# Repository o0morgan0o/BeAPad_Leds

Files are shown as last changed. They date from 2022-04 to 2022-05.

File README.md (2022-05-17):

# BeAPad Led Project

Project for touch sensors combined to Neopixels and RTP Midi for controlling Light and music via midiMessages across wifi.

## Materials:

- ESP32 Microcontroller (WROOM
  DEVKIT_V1) [amazon](https://www.amazon.fr/SP-Cow-ESP-32S-d%C3%A9veloppement-Bluetooth-d%C3%A9nergie/dp/B07VJ34N2Q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) [aliexpress](https://fr.aliexpress.com/item/1005001929935550.html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)
- MPR121 Touch Shield [amazon](https://www.amazon.fr/Adafruit-12-Key-Capacitive-Sensor-Breakout/dp/B00SK8PVNA)
- WS2812E leds [amazon](https://www.amazon.fr/gp/product/B088BRY2SH/ref=ppx_yo_dt_b_asin_title_o07_s00?ie=UTF8&th=1) **<u>MUST BE 60Leds/m for easy soldering on PCB</u>**
- Battery 1100 mAh Lithium 1S 3c
- 1 Capacitor 1000uF
- Steel plates
- Optional : Power Supply 5V 10A or 4 AA Batteries

## Usage

Use RTP-Midi software in windows to listen for midi signals over Wi-Fi.
(software : https://www.tobias-erichsen.de/software/rtpmidi/rtpmidi-tutorial.html)

Set RTP-Midi device to address `192.168.0.4` (address set to client by ESP32 DHCP)

## Ableton Setup

In order to send midi towards the controller, on each midi track, set an instrument rack with:
- External instrument to RTP_Midi Receiver session
- Your drum rack with active notes mentioned in next section

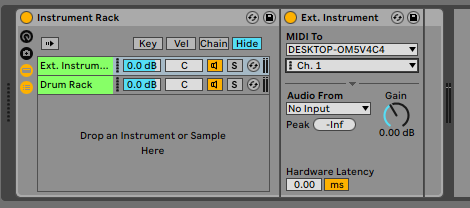
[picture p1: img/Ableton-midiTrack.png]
ableton


### Mapping MidiReceive

```
Each MidiNote Receveid is connected to a specific light effect on board
 _______________________________________
|  | | | |  |  | | | | | |  |  | | | |  |
|  | | | |  |  | | | | | |  |  | | | |  |
|  | | | |  |  | | | | | |  |  | | | |  |
|  |_| |_|  |  |_| |_| |_|  |  |_| |_|  |
|   |   |   |   |   |   |   |   |   |   |
|   |   |   |   |   |   |   |   |   |   |
|___|___|___|___|___|___|___|___|___|___|

TOUCH SENSOR BOARDS ARE CONNECTED TO THE FOLLOWING MIDI NOTES:
  The boards always send the same midiNote:
    -> C4 ( MIDI 60 )      Board 1
    -> C#4 ( MIDI 61 )     Board 2
    -> D4 ( MIDI 62 )      Board 3
    -> D#4 ( MIDI 63 )     Board 4
    -> E4 ( MIDI 64 )      Board 5
    -> F4 ( MIDI 65 )      Board 6
    -> F#4 ( MIDI 66 )     Board 7
    -> G4 ( MIDI 67 )      Board 8
    -> G#4 ( MIDI 68 )     Board 9
    -> A4 ( MIDI 69 )      Board 10
    -> A#4 ( MIDI 70 )     Board 11
    
WHEN SHIFT IS PRESSED (BOARD 12) THE SENSOR BOARDS CAN SEND THESE MIDI NOTES:
    ->  G#6 ( MIDI 80 )     Board 1
    ->  A6 ( MIDI 81 )      Board 2
    ->  A#6 ( MIDI 82 )     Board 3
    ->  B6 ( MIDI 83 )      Board 4
    ->  C7 ( MIDI 84 )      Board 5
    ->  C#7 ( MIDI 85 )     Board 6
    ->  D7 ( MIDI 86 )      Board 7
    ->  D#7 ( MIDI 87 )     Board 8
    ->  E7 ( MIDI 88 )      Board 9
    ->  F7 ( MIDI 89 )      Board 10
    ->  F#7 ( MIDI 90 )     Board 11

*****************************
LIGHT_STRATEGIES PER CHANNEL:
-> One color per channel
*****************************
    CHANNEL 1 | FULL_LIGHT
    CHANNEL 2 | FADE_OUT
    CHANNEL 3 | SERPENTIN
    CHANNEL 4 | FLASH_TOWARDS_EXTERIOR
    CHANNEL 5 | NOTHING YET
    CHANNEL 6 | NOTHING YET
    CHANNEL 7 | NOTHING YET
    CHANNEL 8 | NOTHING YET
    
******************************
SPECIAL EFFECTS
-> Color can be change by midi_note value
-> Luminosity can be change by velocity value
******************************

    CHANNEL 9  | STROMBOSCOPE
    CHANNEL 10 | NOTHING YET
    CHANNEL 11 | NOTHING YET
    CHANNEL 12 | NOTHING YET
    CHANNEL 13 | NOTHING YET
    CHANNEL 14 | NOTHING YET
    CHANNEL 15 | NOTHING YET
    CHANNEL 16 | NOTHING YET

```

## Hardware

### LedBoards:

(See EasyEDA project in "Resources_PCB_Schematics")

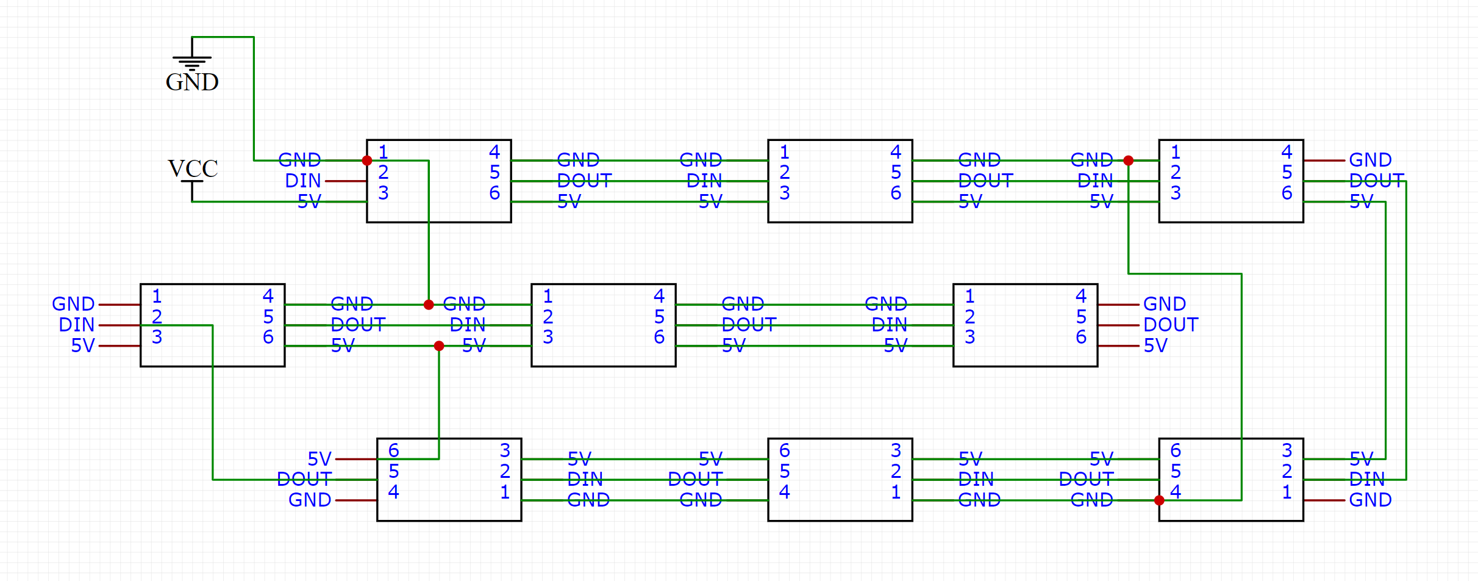
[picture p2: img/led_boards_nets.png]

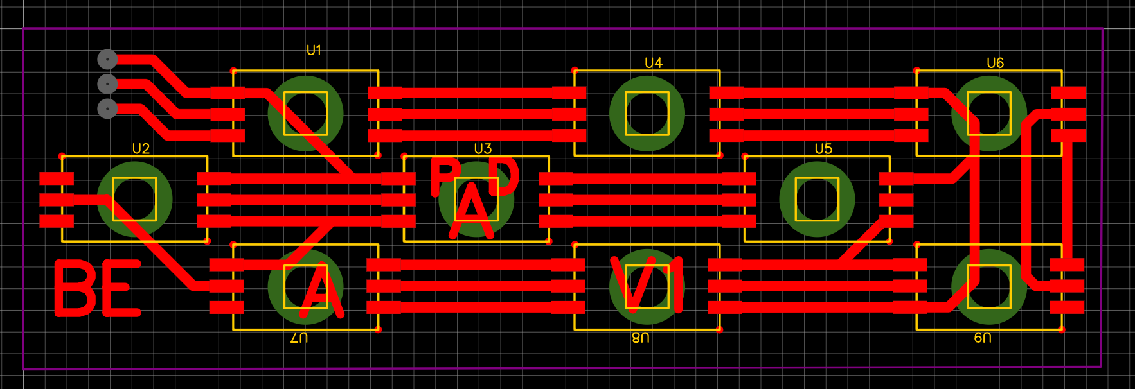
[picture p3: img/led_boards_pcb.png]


**Warning: Orientation of led change across the board (see real reference below)**

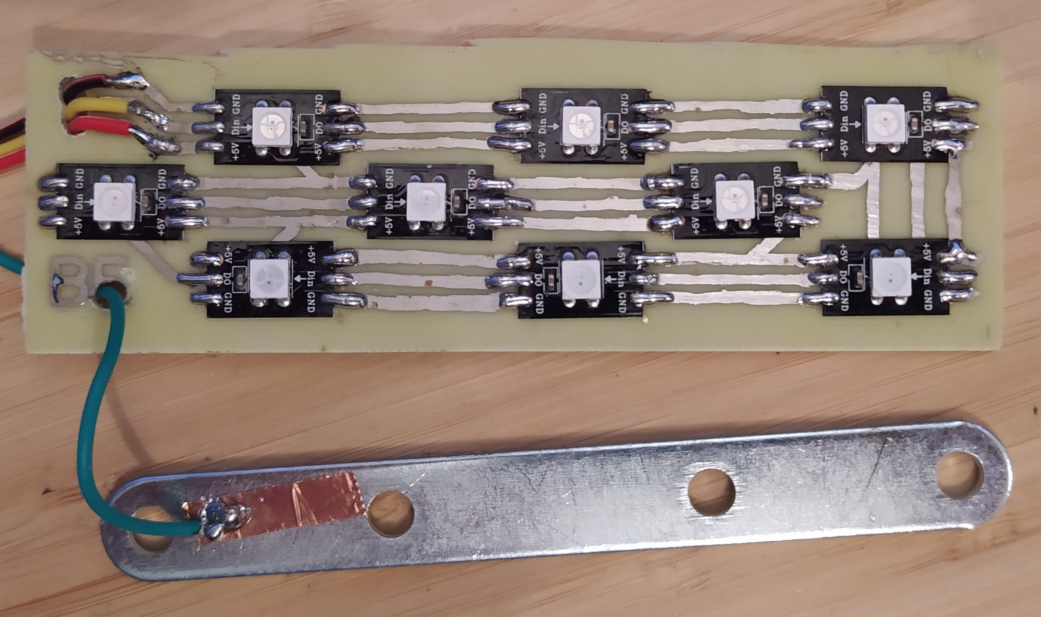
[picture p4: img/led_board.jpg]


### Controller Board

(See KiCad project in "Resources_PCB_Schematics")

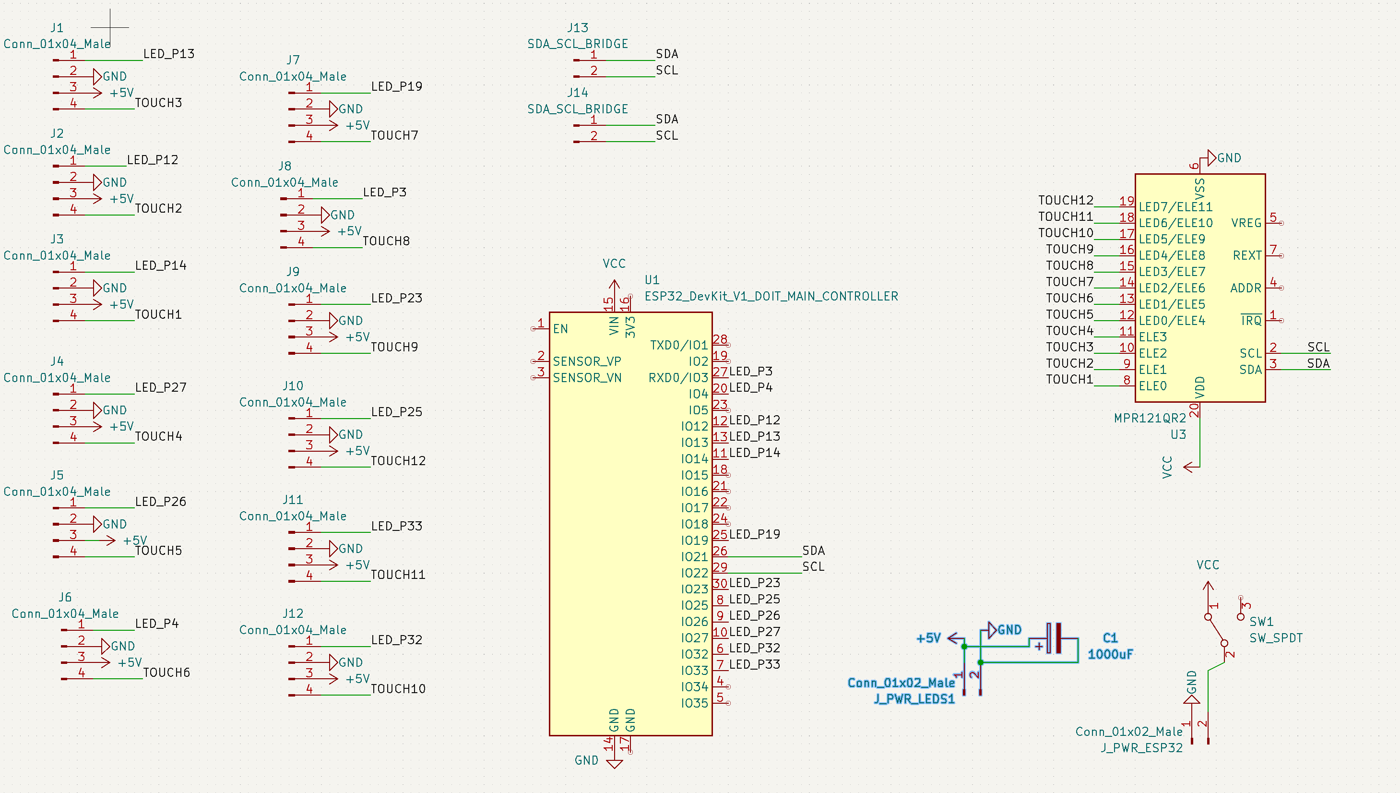
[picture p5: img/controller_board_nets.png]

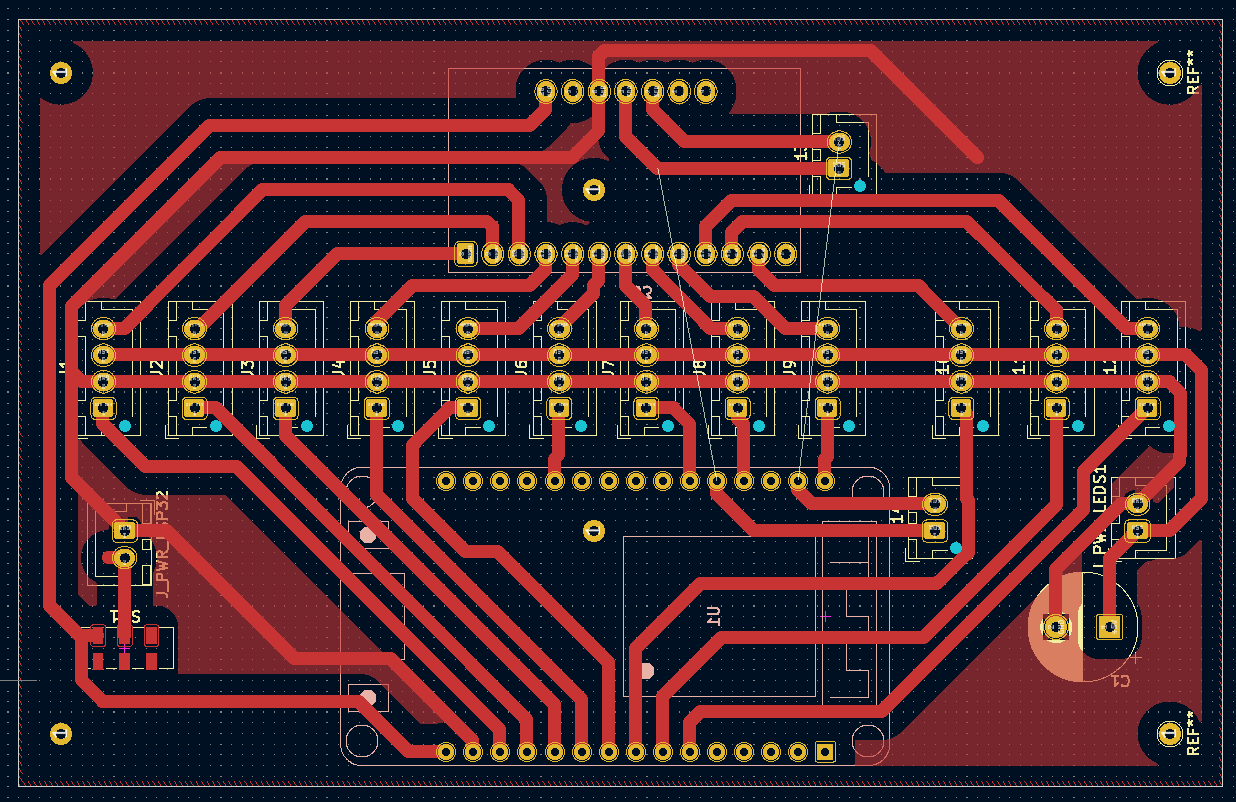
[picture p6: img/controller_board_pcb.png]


**Real prototype**

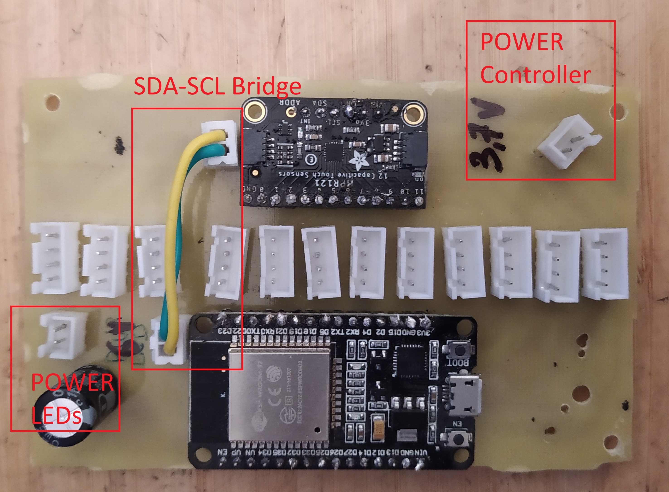
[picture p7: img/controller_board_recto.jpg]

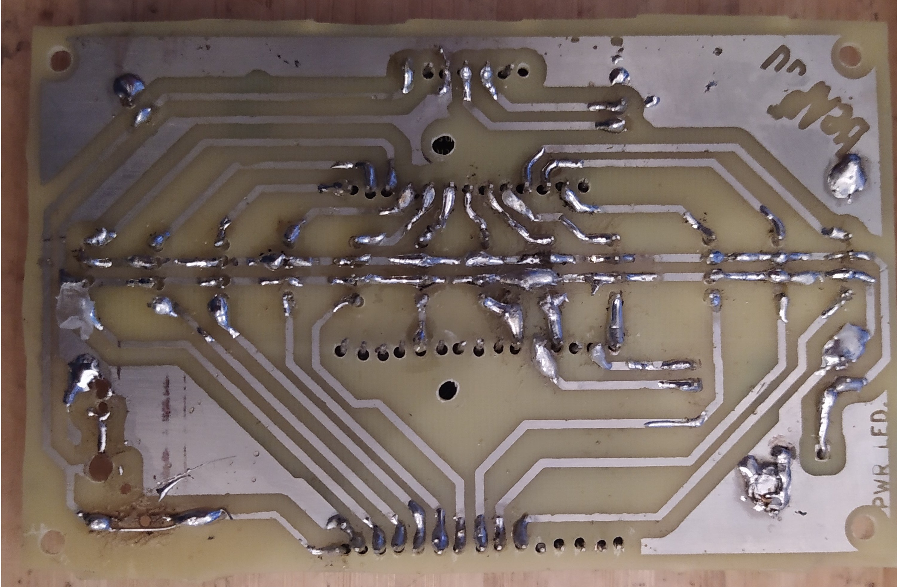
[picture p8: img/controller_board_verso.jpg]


### 3D Models

Very basic holders can be found in Resources_3D_printing.

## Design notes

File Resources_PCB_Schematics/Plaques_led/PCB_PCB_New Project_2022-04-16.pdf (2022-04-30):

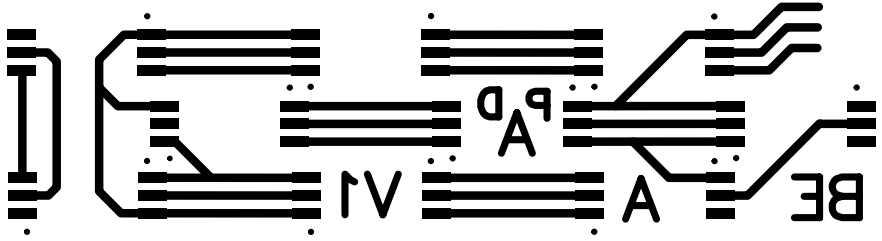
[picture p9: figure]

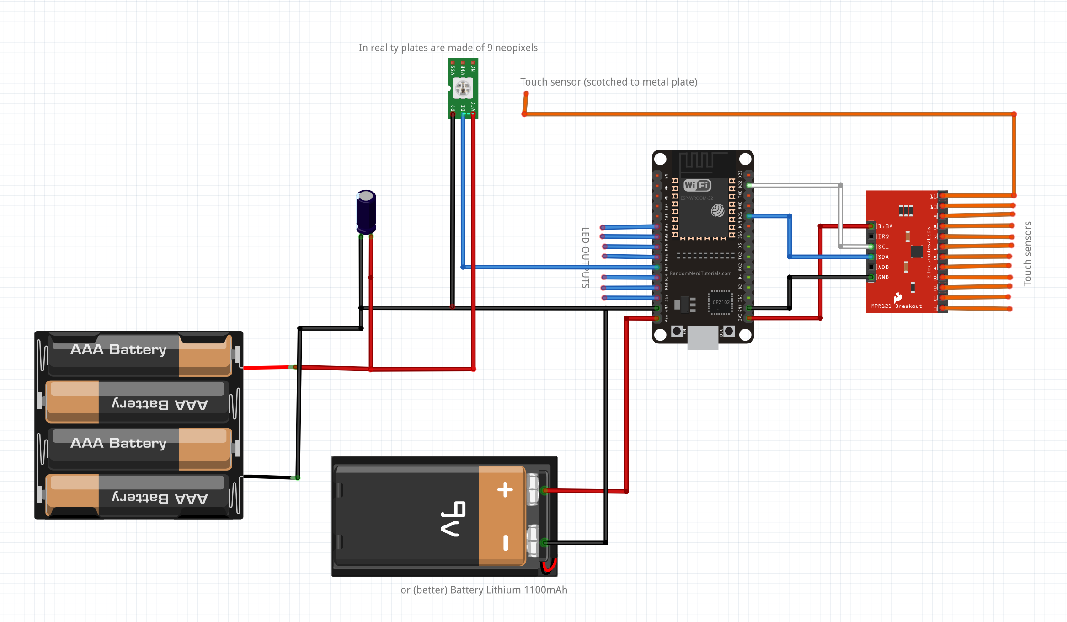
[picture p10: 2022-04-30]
Resources_PCB_Schematics/schema_cablages.png

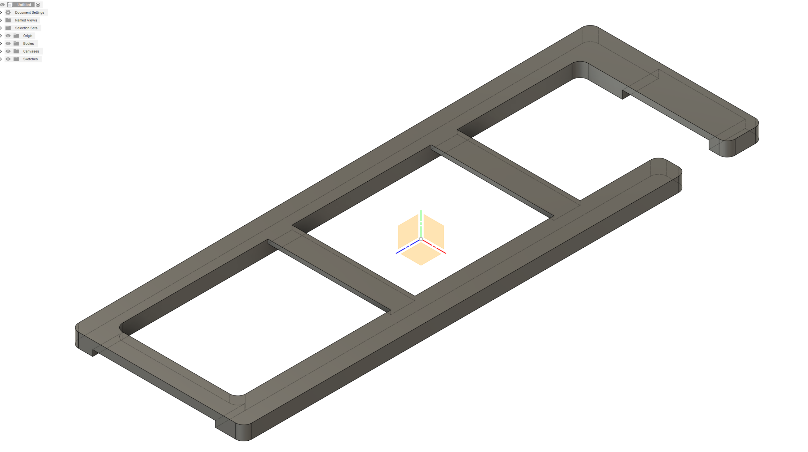
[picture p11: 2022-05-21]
img/calage-plaques.png

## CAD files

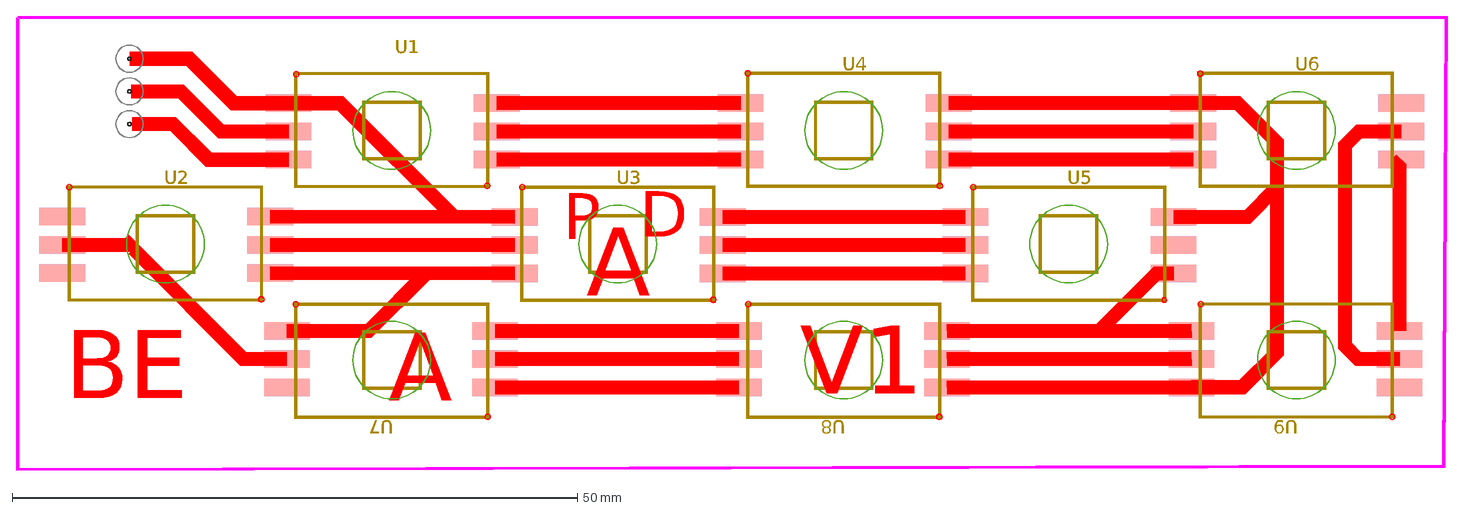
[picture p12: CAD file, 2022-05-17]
Resources_PCB_Schematics/Plaques_led/PCB_New Project_2022-05-17.dxf
BE
A
P
D
V1
U1
U2
U3
U4
U5
U6
U7
U8
U9

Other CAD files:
Resources_3D_printing/Calage_plaques.f3d

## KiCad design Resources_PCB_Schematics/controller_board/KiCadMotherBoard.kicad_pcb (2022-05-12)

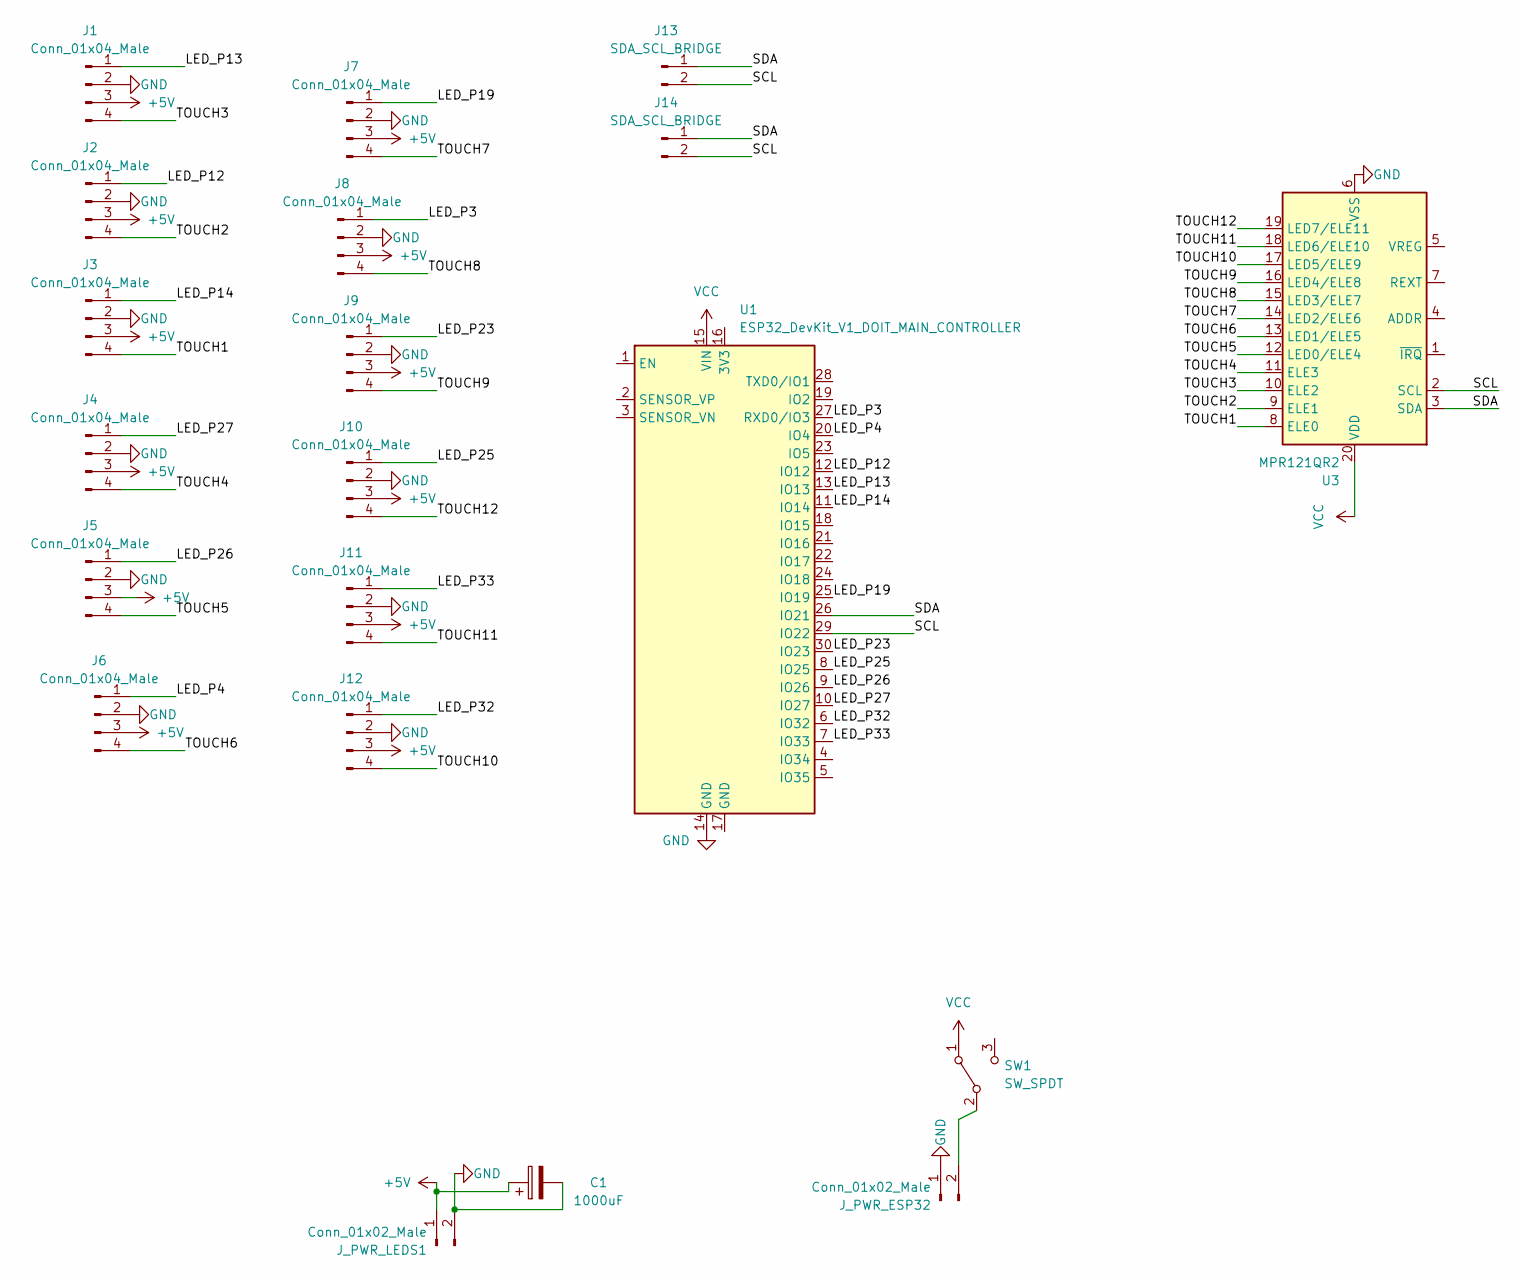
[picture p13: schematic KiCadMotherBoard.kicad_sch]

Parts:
C1: 1000uF; CP_Radial_D10.0mm_P5.00mm
J1, J2, J3, J4, J5, J6, J7, J8, J9, J10, J11, J12: Conn_01x04_Male; JST_XH_B4B-XH-AM_1x04_P2.50mm_Vertical
J13, J14: SDA_SCL_BRIDGE; JST_XH_B2B-XH-AM_1x02_P2.50mm_Vertical
J_PWR_ESP32: Conn_01x02_Male; JST_XH_B2B-XH-A_1x02_P2.50mm_Vertical
J_PWR_LEDS1: Conn_01x02_Male; JST_XH_B2B-XH-A_1x02_P2.50mm_Vertical
SW1: SW_SPDT; SW_DPDT_CK_JS202011JCQN
U1: ESP32_DevKit_V1_DOIT_MAIN_CONTROLLER; esp32_devkit_v1_doit
U3: MPR121QR2; custom-mpr121

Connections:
+5V: C1.1, J1.3, J2.3, J3.3, J4.3, J5.3, J6.3, J7.3, J8.3, J9.3, J10.3, J11.3, J12.3, J_PWR_LEDS1.1
/LED_P3: J8.1, U1.27 (RXD0/IO3)
/LED_P4: J6.1, U1.20 (IO4)
/LED_P12: J2.1, U1.12 (IO12)
/LED_P13: J1.1, U1.13 (IO13)
/LED_P14: J3.1, U1.11 (IO14)
/LED_P19: J7.1, U1.25 (IO19)
/LED_P23: J9.1, U1.30 (IO23)
/LED_P25: J10.1, U1.8 (IO25)
/LED_P26: J5.1, U1.9 (IO26)
/LED_P27: J4.1, U1.10 (IO27)
/LED_P32: J12.1, U1.6 (IO32)
/LED_P33: J11.1, U1.7 (IO33)
/SCL: J13.2, J14.2, U1.29 (IO22), U3.2 (SCL)
/SDA: J13.1, J14.1, U1.26 (IO21), U3.3 (SDA)
/TOUCH1: J3.4, U3.8 (ELE0)
/TOUCH2: J2.4, U3.9 (ELE1)
/TOUCH3: J1.4, U3.10 (ELE2)
/TOUCH4: J4.4, U3.11 (ELE3)
/TOUCH5: J5.4, U3.12 (LED0/ELE4)
/TOUCH6: J6.4, U3.13 (LED1/ELE5)
/TOUCH7: J7.4, U3.14 (LED2/ELE6)
/TOUCH8: J8.4, U3.15 (LED3/ELE7)
/TOUCH9: J9.4, U3.16 (LED4/ELE8)
/TOUCH10: J12.4, U3.17 (LED5/ELE9)
/TOUCH11: J11.4, U3.18 (LED6/ELE10)
/TOUCH12: J10.4, U3.19 (LED7/ELE11)
GND: C1.2, J1.2, J2.2, J3.2, J4.2, J5.2, J6.2, J7.2, J8.2, J9.2, J10.2, J11.2, J12.2, J_PWR_ESP32.1, J_PWR_LEDS1.2, U1.14 (GND), U3.6 (VSS)
unnamed: J_PWR_ESP32.2, SW1.2 (B)
VCC: SW1.1 (A), U1.15 (VIN), U3.20 (VDD)

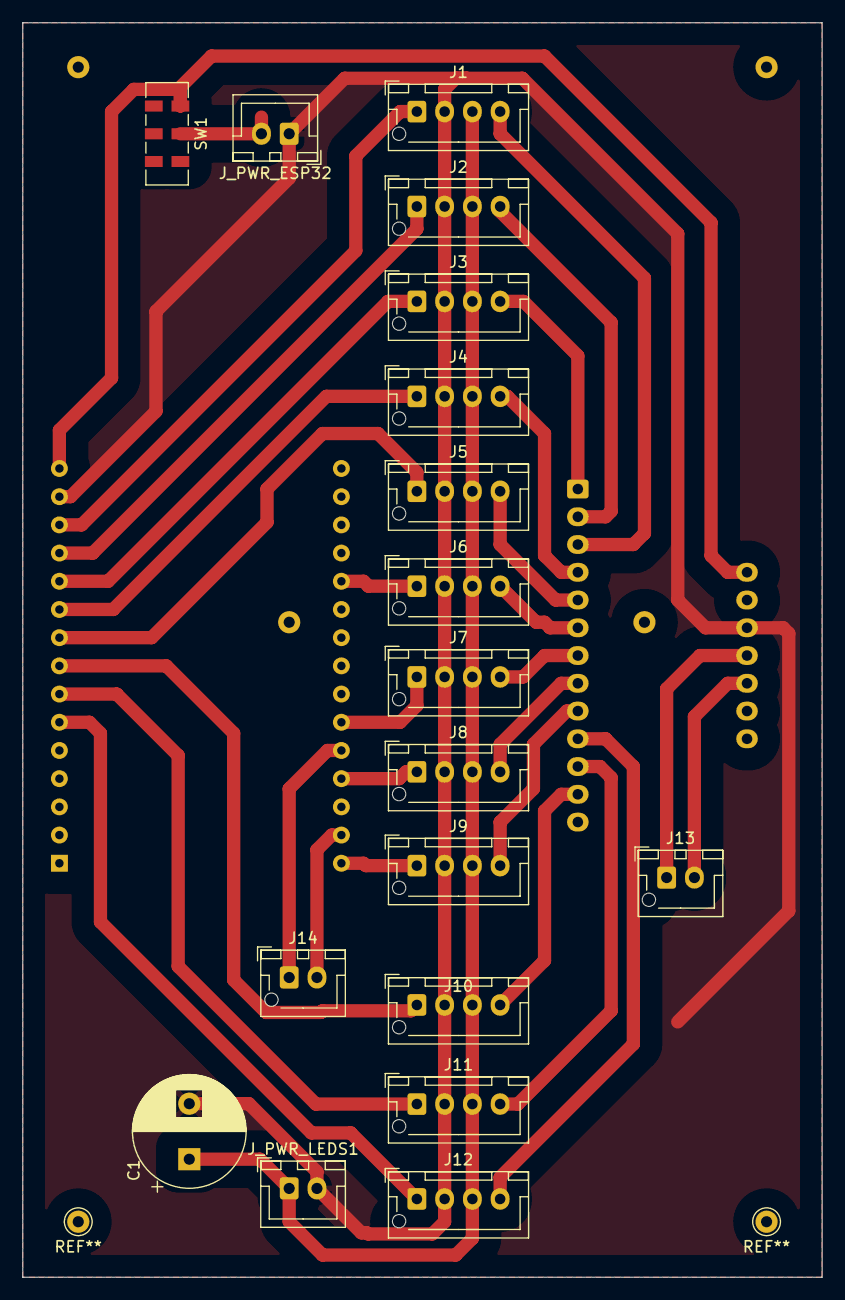
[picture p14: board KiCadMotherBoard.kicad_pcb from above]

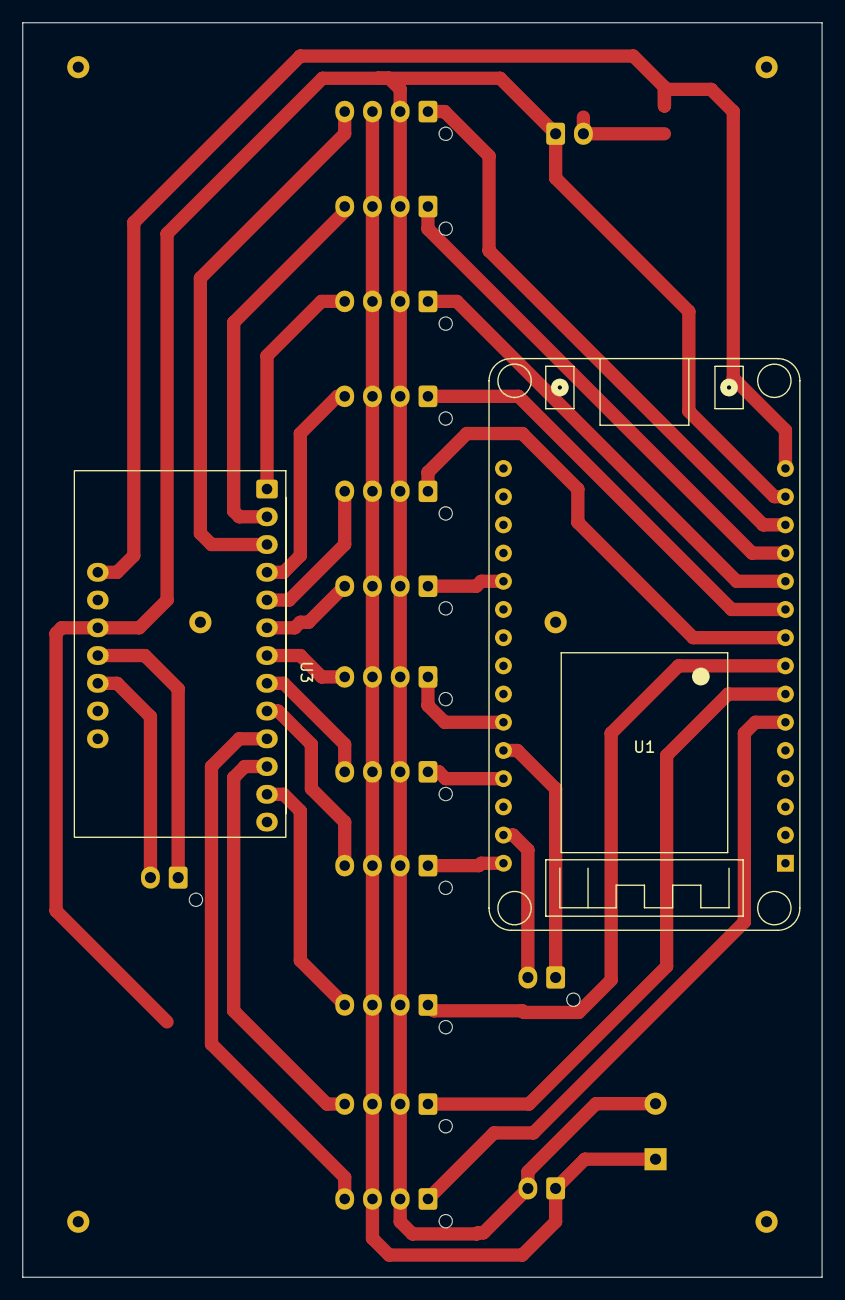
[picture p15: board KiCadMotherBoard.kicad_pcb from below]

Board: 2 copper layers, 72.0 x 113.0 mm, 20 parts (2 on the bottom side), 30 nets.

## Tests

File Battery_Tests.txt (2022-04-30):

Program:
Blend -> CRGB:AliceBlue -> CRGB:Red

	ESP32 USB Power
	Leds : 4 AA lr6 Eco+
		=> 80 min couleurs deviennents vertes et rougae
		=> 120 min jaune et rouge. Affaiblissement important
		=> 140 min leds complétements rouges

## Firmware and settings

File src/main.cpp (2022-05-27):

/**
 * BeAPadProject
 * Morgan Thibert - 2022
 *
 * MidiController with with communication via RTP-Midi on Wifi controlled by capacitive sensors
 *
 * Interesting resources:
 * http://ww1.microchip.com/downloads/en/Appnotes/Capacitive-Touch-Sensor-Design-Guide-DS00002934-B.pdf
 */

#include <AppleMidi.h>
#include <WiFiUdp.h>
#include "AccessPoint.h"
#include "Debug_Helper.h"
#include "LightStrategy_Factory.h"
#include "MidiKeyReceiver.h"
#include "Midi_Handler.h"
#include "Debug_Helper_Serial.h"
#include "Debug_Helper_Inactive.h"
#include "RTP_Midi_MidiHandler.h"
#include "DebugHelper_WebSocket.h"
#include "MidiKeySender.h"
#include <Wire.h>
#include "LedBoard_Store_NeoPixelStore.h"
#include "NeoPixelBoard.h"
#include "NeoPixelBoardsManager.h"
#include "CapacitiveTouch_Dispatcher.h"
#include "Capacitive_Sensor.h"
#include "MPR121_Sensor.h"
#include "main_constants.h"

#define MPR_TOUCH_PIN_CONNECTED_TO_BOARD_0 2
#define MPR_TOUCH_PIN_CONNECTED_TO_BOARD_1 1
#define MPR_TOUCH_PIN_CONNECTED_TO_BOARD_2 0
#define MPR_TOUCH_PIN_CONNECTED_TO_BOARD_3 3
#define MPR_TOUCH_PIN_CONNECTED_TO_BOARD_4 4
#define MPR_TOUCH_PIN_CONNECTED_TO_BOARD_5 5
#define MPR_TOUCH_PIN_CONNECTED_TO_BOARD_6 6
#define MPR_TOUCH_PIN_CONNECTED_TO_BOARD_7 7
#define MPR_TOUCH_PIN_CONNECTED_TO_BOARD_8 8
#define MPR_TOUCH_PIN_CONNECTED_TO_BOARD_9 11
#define MPR_TOUCH_PIN_CONNECTED_TO_BOARD_10 10
APPLEMIDI_CREATE_INSTANCE(WiFiUDP, AppleMIDI, "AppleMIDI-ESP32", DEFAULT_CONTROL_PORT);
//
AccessPoint *accessPoint;
Debug_Helper *debugHelper;
Debug_Helper *inactiveDebugHelper;
LedBoard_Store_Interface *ledBoardStore;
LedBoardsManager *ledBoardsManager;
LightStrategy_Factory *lightStrategyFactory;
SpecialEffect_Factory *specialEffectFactory;
MidiKeyReceiver *midiReceiver;
MidiKeySender *midiSender;
ICapacitiveTouch_Dispatcher *capacitiveTouchDispatcher;
Midi_Handler *midiHandler;
Capacitive_Sensor *touchSensor;

void setup() {

  // **************************
  // DEBUG HELPER
  //    debugHelper = new Debug_Helper();
  //    debugHelper = new Debug_Helper_Inactive();
  //    debugHelper = new DebugHelper_WebSocket();
  //    debugHelper = new Debug_Helper_Serial();
  // COMMENT FOLLOWING 2 LINES TO REACTIVATE DEBUG MODE
  inactiveDebugHelper = new Debug_Helper_Inactive();
  debugHelper = inactiveDebugHelper;

  // *************************
  // ACCESS POINT
  accessPoint = new AccessPoint();

  // **************************
  // CREATION OF LIGHT STRATEGY AND SPECIAL EFFECTS FACTORY
  lightStrategyFactory = new LightStrategy_Factory();
  specialEffectFactory = new SpecialEffect_Factory();

  // **************************
  // ADD BOARDS TO STORE
  // NeoPixelBoard 1st param = GPIO Pin
  ledBoardStore = new LedBoard_Store_NeoPixelStore();
  uint8_t NUM_PIXELS_PER_BOARD = 9;
  // NOTE : VERY IMPORTANT TO KEEP THE SAME ORDER OF THE PCB
  ledBoardStore->addBoard(new NeoPixelBoard(32, NUM_PIXELS_PER_BOARD, lightStrategyFactory));
  ledBoardStore->addBoard(new NeoPixelBoard(33, NUM_PIXELS_PER_BOARD, lightStrategyFactory));
  ledBoardStore->addBoard(new NeoPixelBoard(25, NUM_PIXELS_PER_BOARD, lightStrategyFactory));
  ledBoardStore->addBoard(new NeoPixelBoard(23, NUM_PIXELS_PER_BOARD, lightStrategyFactory));
  ledBoardStore->addBoard(new NeoPixelBoard(3, NUM_PIXELS_PER_BOARD, lightStrategyFactory));
  ledBoardStore->addBoard(new NeoPixelBoard(19, NUM_PIXELS_PER_BOARD, lightStrategyFactory));
  ledBoardStore->addBoard(new NeoPixelBoard(4, NUM_PIXELS_PER_BOARD, lightStrategyFactory));
  ledBoardStore->addBoard(new NeoPixelBoard(26, NUM_PIXELS_PER_BOARD, lightStrategyFactory));
  ledBoardStore->addBoard(new NeoPixelBoard(27, NUM_PIXELS_PER_BOARD, lightStrategyFactory));
  ledBoardStore->addBoard(new NeoPixelBoard(14, NUM_PIXELS_PER_BOARD, lightStrategyFactory));
  ledBoardStore->addBoard(new NeoPixelBoard(12, NUM_PIXELS_PER_BOARD, lightStrategyFactory));
  ledBoardStore->addBoard(new NeoPixelBoard(13, NUM_PIXELS_PER_BOARD, lightStrategyFactory));

  // **************************
  // INITIALIZE BOARD MANAGER
  ledBoardsManager = new NeoPixelBoardsManager(ledBoardStore, lightStrategyFactory, specialEffectFactory,
											   debugHelper);
  ledBoardsManager->init();
  ledBoardsManager->giveAllBoardsReferenceOfManager();

  // *************************
  // DEFINITIONS OF STRATEGY FOR EACH BOARD
  // Channel musts be in range 1 - 8

  // *************************************************************************
  // *************************************************************************
  // GONZY !!! C'est ICI QUE TU CHANGES LES COULEURS
  // DDDDDDDDDDDDDDDDDDDDDDDDDDDDDDDDDDDDDDDDDDDDDDDDDDDDDDDD
  // DDDDDDDDDDDDDDDDDDDDDDDDDDDDDDDDDDDDDDDDDDDDDDDDDDDDDDDD
  // DDDDDDDDDDDDDDDDDDDDDDDDDDDDDDDDDDDDDDDDDDDDDDDDDDDDDDDD
  // DDDDDDDDDDDDDDDDDDDDDDDDDDDDDDDDDDDDDDDDDDDDDDDDDDDDDDDD
  // DDDDDDDDDDDDDDDDDDDDDDDDDDDDDDDDDDDDDDDDDDDDDDDDDDDDDDDD
  // DDDDDDDDDDDDDDDDDDDDDDDDDDDDDDDDDDDDDDDDDDDDDDDDDDDDDDDD
  // DDDDDDDDDDDDDDDDDDDDDDDDDDDDDDDDDDDDDDDDDDDDDDDDDDDDDDDD
  // DDDDDDDDDDDDDDDDDDDDDDDDDDDDDDDDDDDDDDDDDDDDDDDDDDDDDDDD
  // DDDDDDDDDDDDDDDDDDDDDDDDDDDDDDDDDDDDDDDDDDDDDDDDDDDDDDDD
  // List of Predefined color names : https://github.com/FastLED/FastLED/wiki/Pixel-reference
  // Colors can be changed here by hexValue CRGB{0xffffff}, or by predefined Colors CRGB::Red, or by rgb values CRGB{255,255,0};
  ledBoardsManager->setLightStrategyForChannel(1, LIGHT_STRATEGIES::STRATEGY_FULL_LIGHT, CRGB::Red);
  ledBoardsManager->setLightStrategyForChannel(2, LIGHT_STRATEGIES::STRATEGY_FADE_OUT, CRGB{60,87,13});
  ledBoardsManager->setLightStrategyForChannel(3, LIGHT_STRATEGIES::STRATEGY_SERPENTIN, CRGB{76,125,117});
  ledBoardsManager->setLightStrategyForChannel(4, LIGHT_STRATEGIES::STRATEGY_FLASH_TOWARDS_EXTERIOR, CRGB::BlueViolet);
  ledBoardsManager->setShiftColor(CRGB::White); // Shift Color
  // *************************************************************************
  // *************************************************************************

  // TODO : Make more Strategies
  // STRATEGY_FADE_OUT_SLOW
  // STRATEGY_EXPANSION FROM CENTER TO EXTERIOR
  // SPECIAL_EFFECTS GLOBAL WAVE

  // **************************
  // DEFINITIONS OF SPECIAL EFFECTS STRATEGY
  // Channel must be in range 9 - 16
  // Special Effects Strategy don't need color. Special Effects handled HSV Colors, where:
  // H (color tone) is set by noteNumber
  // S (color saturation) is fixed at arbitrary value
  // V (color luminosity) is set by velocity
  ledBoardsManager->setSpecialEffectStrategyForChannel(9, SPECIAL_EFFECT_STRATEGY::SPECIAL_EFFECT_STROMBOSCOPE);

  // ****************************
  // MIDI KEY RECEIVER
  // explanations: connectBoardToReceiveMidiKey(60, 0);
  // it means when MidiNote 60 is received a triggerOnSignalIsSendOn board 0
  midiReceiver = new MidiKeyReceiver(ledBoardsManager, inactiveDebugHelper);
  midiReceiver->connectBoardToReceiveMidiKey(0, 60);
  midiReceiver->connectBoardToReceiveMidiKey(1, 61);
  midiReceiver->connectBoardToReceiveMidiKey(2, 62);
  midiReceiver->connectBoardToReceiveMidiKey(3, 63);
  midiReceiver->connectBoardToReceiveMidiKey(4, 64);
  midiReceiver->connectBoardToReceiveMidiKey(5, 65);
  midiReceiver->connectBoardToReceiveMidiKey(6, 66);
  midiReceiver->connectBoardToReceiveMidiKey(7, 67);
  midiReceiver->connectBoardToReceiveMidiKey(8, 68);
  midiReceiver->connectBoardToReceiveMidiKey(9, 69);
  midiReceiver->connectBoardToReceiveMidiKey(10, 70);

  // ***************************
  // MIDI KEY SENDER
  // explanations : connectBoardToSendMidiKey(1, 4 ,87)
  // it means that touchPin1 (in MPR121) is connected to board 4
  // ,and it will send midiNote 87 when touched
  // Last board (11 from index 0) is not connected to midiSend or touchPin because it acts as a shift button
  midiSender = new MidiKeySender(ledBoardsManager, debugHelper);
  midiSender->connectBoardToSendMidiKey(MPR_TOUCH_PIN_CONNECTED_TO_BOARD_0, 0, 60, 80);
  midiSender->connectBoardToSendMidiKey(MPR_TOUCH_PIN_CONNECTED_TO_BOARD_1, 1, 61, 81);
  midiSender->connectBoardToSendMidiKey(MPR_TOUCH_PIN_CONNECTED_TO_BOARD_2, 2, 62, 82);
  midiSender->connectBoardToSendMidiKey(MPR_TOUCH_PIN_CONNECTED_TO_BOARD_3, 3, 63, 83);
  midiSender->connectBoardToSendMidiKey(MPR_TOUCH_PIN_CONNECTED_TO_BOARD_4, 4, 64, 84);
  midiSender->connectBoardToSendMidiKey(MPR_TOUCH_PIN_CONNECTED_TO_BOARD_5, 5, 65, 85);
  midiSender->connectBoardToSendMidiKey(MPR_TOUCH_PIN_CONNECTED_TO_BOARD_6, 6, 66, 86);
  midiSender->connectBoardToSendMidiKey(MPR_TOUCH_PIN_CONNECTED_TO_BOARD_7, 7, 67, 87);
  midiSender->connectBoardToSendMidiKey(MPR_TOUCH_PIN_CONNECTED_TO_BOARD_8, 8, 68, 88);
  midiSender->connectBoardToSendMidiKey(MPR_TOUCH_PIN_CONNECTED_TO_BOARD_9, 9, 69, 89);
  midiSender->connectBoardToSendMidiKey(MPR_TOUCH_PIN_CONNECTED_TO_BOARD_10, 10, 70, 90);
  midiSender->connectBoardToSendMidiKey(MPR_TOUCH_PIN_CONNECTED_TO_BOARD_11_SHIFT_PIN, 11, NO_MIDI_TRIGGER_FOR_BOARD,
										NO_MIDI_TRIGGER_FOR_BOARD);

  // **************************
  // RTP_MIDI
  midiHandler = new RTP_Midi_MidiHandler(midiReceiver, midiSender, debugHelper, &AppleMIDI, &AppleAppleMIDI);
  midiHandler->init();
  // set eventListeners
  // TODO implements MIDI_CC change (maybe for controlling the colors)
  AppleMIDI.setHandleNoteOn([](byte channel, byte note, byte velocity) {
	// channels [1 - 8] are reserved for lightStrategies
	// channels [9 - 16] are reserved for special effects
	if (channel <= 8) midiHandler->handleOn(channel, note, velocity);
	else midiHandler->handleOnSpecialEffect(channel, note, velocity);
  });
  AppleMIDI.setHandleNoteOff([](byte channel, byte note, byte velocity) {
	if (channel <= 8) midiHandler->handleNoteOff(channel, note, velocity);
	else midiHandler->handleOffSpecialEffect(channel, note, velocity);
  });
  AppleAppleMIDI.setHandleConnected([](const APPLEMIDI_NAMESPACE::ssrc_t &ssrc, const char *name) {
	ledBoardsManager->showBlinkHighPriorityMessage(BlinkHighPriorityMessages::RTP_CONNECTION_SUCCESS);
	midiHandler->handleConnected();
  });
  AppleAppleMIDI.setHandleDisconnected([](const APPLEMIDI_NAMESPACE::ssrc_t &ssrc) {
	ledBoardsManager->showBlinkHighPriorityMessage(BlinkHighPriorityMessages::RTP_CONNECTION_LOST);
	midiHandler->handleDisconnected();
  });

  // **************************
  // TOUCH SENSORS INIT (MPR121)
  // Following strategies are chosen arbitrarily (except for the shift_key_strategy). They can be used when the device is not midi connected
  touchSensor = new MPR121_Sensor();

  // **************************
  // CAPACITIVE TOUCH DISPATCHER
  capacitiveTouchDispatcher = new CapacitiveTouch_Dispatcher(ledBoardsManager, midiHandler, debugHelper, touchSensor);
  capacitiveTouchDispatcher->begin();
  // THRESHOLD: read documentation of MPR121 about the handling of thresholds
  // helpful thread about this : https://forums.adafruit.com/viewtopic.php?t=72025
  // If default values ard OK, comment following line
  // capacitiveTouchDispatcher->setThresholds(20, 10);
  // the following strategies can be ignored because are for use only if no rtp midi is connected
  capacitiveTouchDispatcher->setTriggerOnTouchLightStrategyOnBoard(0, LIGHT_STRATEGIES::STRATEGY_FADE_OUT);
  capacitiveTouchDispatcher->setTriggerOnTouchLightStrategyOnBoard(1, LIGHT_STRATEGIES::STRATEGY_FADE_OUT);
  capacitiveTouchDispatcher->setTriggerOnTouchLightStrategyOnBoard(2, LIGHT_STRATEGIES::STRATEGY_FADE_OUT);
  capacitiveTouchDispatcher->setTriggerOnTouchLightStrategyOnBoard(3, LIGHT_STRATEGIES::STRATEGY_FADE_OUT);
  capacitiveTouchDispatcher->setTriggerOnTouchLightStrategyOnBoard(4, LIGHT_STRATEGIES::STRATEGY_FADE_OUT);
  capacitiveTouchDispatcher->setTriggerOnTouchLightStrategyOnBoard(5, LIGHT_STRATEGIES::STRATEGY_FADE_OUT);
  capacitiveTouchDispatcher->setTriggerOnTouchLightStrategyOnBoard(6, LIGHT_STRATEGIES::STRATEGY_FADE_OUT);
  capacitiveTouchDispatcher->setTriggerOnTouchLightStrategyOnBoard(7, LIGHT_STRATEGIES::STRATEGY_FADE_OUT);
  capacitiveTouchDispatcher->setTriggerOnTouchLightStrategyOnBoard(10, LIGHT_STRATEGIES::STRATEGY_FADE_OUT);
  capacitiveTouchDispatcher->setTriggerOnTouchLightStrategyOnBoard(11, LIGHT_STRATEGIES::STRATEGY_SHIFT_KEY_STRATEGY);

  // ***************************
  // ACCESS POINT SERVER INIT
  accessPoint->init(ledBoardsManager, inactiveDebugHelper);

  // *************************
  // FINALIZE INITIALISATION
  ledBoardsManager->reinitBoardsLightStrategies();
  ledBoardsManager->showBlinkHighPriorityMessage(BlinkHighPriorityMessages::SHOW_END_OF_SETUP_MESSAGE);

}

void loop() {

  // can be deactivated if webServer Not Needed
  //    accessPoint->loop();

  // check midi Messages
  midiHandler->loop();

  // capacitiveTouch loop
  capacitiveTouchDispatcher->loop();

  // updateValues and show LedBoardManager
  ledBoardsManager->update(millis());
  ledBoardsManager->show();

}

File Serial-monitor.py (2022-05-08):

import serial
from time import sleep
import sys

COM = 'COM8'  # /dev/ttyACM0 (Linux)
BAUD = 115200

ser = serial.Serial(COM, BAUD, timeout=.1)

print('Waiting for device');
# sleep(3)
print(ser.name)

# check args
if ("-m" in sys.argv or "--monitor" in sys.argv):
    monitor = True
else:
    monitor = False

while True:
    val = str(ser.readline().decode().strip('\r\n'))  # Capture serial output as a decoded string
    valA = val.split("/")
    # print()
    if (monitor == True):
        if val != "":
            print(val, end="\r\n", flush=True)

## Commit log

2022-04-23 functional prototype
2022-04-26 [fix] switch to Sync WebServer
2022-04-30 [intermediary] intermediary commit
    [Calage_plaques.f3d]
2022-05-01 [intermediary] example functional on one led
2022-05-05 update pcb sketches
2022-05-08 Moved to adafruit Neopixel Library, more tests to do. Fast led don't work
    [KiCadMotherBoard.kicad_pcb, KiCadMotherBoard.kicad_sch]
2022-05-09 [feature] Preparing docs and added TODO for multiple trigger boards on same Midi Note
2022-05-12 add light all boards on shift
    [KiCadMotherBoard.kicad_pcb]
2022-05-17 updated doc + bug fix in main.cpp
    [main.cpp]
2022-05-17 add feature set-threshold for touch and add documentation
    [KiCadMotherBoard.kicad_pcb, KiCadMotherBoard.kicad_sch, KiCadMotherBoard_oneController.kicad_sch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]
2022-05-21 add ableton live example set
    [Project8_1.cfg]
